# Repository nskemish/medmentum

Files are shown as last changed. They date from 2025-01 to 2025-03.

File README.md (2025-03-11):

<p align="center">
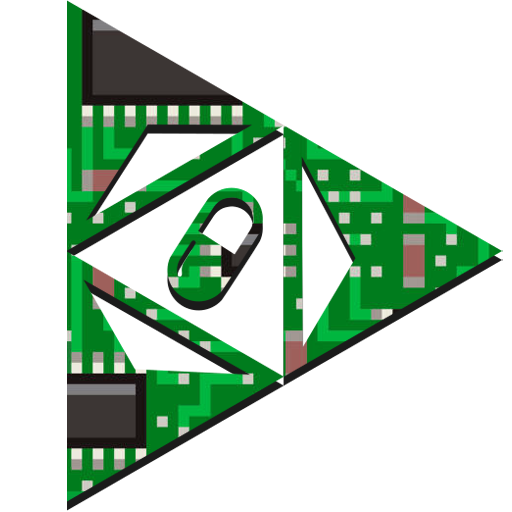
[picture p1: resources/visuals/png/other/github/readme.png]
  
</p>
<div align="center" id="toc">
  <ul style="list-style: none">
    <summary>
      <h1>MedMentum</h1><br>
      <h3 align="center">Automatski dozer za lekove</h3>
    </summary>
  </ul>
</div>

---

# Šta je to MedMentum?
**MedMentum** je revolucionarni sistem za automatsko doziranje lekova, osmišljen da transformiše način na koji pacijenti i zdravstveni radnici pristupaju terapijama. Ovaj inovativni uređaj kombiniuje najsavremeniju tehnologiju sa intuitivnim dizajnom kako bi omogućio precizno, sigurno i jednostavno doziranje lekova. MedMentum ne samo da olakšava svakodnevno uzimanje terapija, već i smanjuje rizik od ljudskih grešaka, čineći medicinsku negu pouzdanijom i efikasnijom. 💊✨

## Naša misija 

Naša misija je da revolucionišemo proces primene terapija kroz tehnološke inovacije. Želimo da smanjimo broj grešaka u doziranju lekova, povećamo svest o važnosti pravilnog uzimanja terapija i omogućimo pacijentima veću samostalnost u upravljanju svojim zdravljem. MedMentum je više od uređaja – to je alat koji podržava pacijente i zdravstvene radnike, čineći svakodnevne terapije jednostavnijim, sigurnijim i pristupačnijim. 

## Ciljevi 

1. **Preciznost**: MedMentum obezbeđuje tačno doziranje lekova u skladu sa propisanom terapijom, eliminišući mogućnost ljudske greške.   
2. **Sigurnost**: Pametni sigurnosni mehanizmi sprečavaju predoziranje ili propustanje doze, čime se povećava bezbednost pacijenata.   
3. **Pristupačnost**: Dizajniran je da bude jednostavan za korišćenje, kako bi odgovarao pacijentima svih uzrasta i zdravstvenih stanja.   
4. **Pouzdanost**: MedMentum pruža konzistentnu podršku, omogućavajući pacijentima da se oslanjaju na uređaj u svakodnevnom životu.   

## Ključne karakteristike 

- **Pametni uređaj za automatsko doziranje**: MedMentum automatski odmerava i dozira lekove prema unapred podešenom planu terapije. 
- **Integracija sa mobilnom aplikacijom**: Pacijenti i zdravstveni radnici mogu pratiti terapiju, primati podsetnici i prilagođavati doze putem jednostavne mobilne aplikacije.   
- **Notifikacije i podsetnici**: Sistem šalje obaveštenja za vreme uzimanja lekova, čime se smanjuje rizik od zaboravljanja. 
- **Sigurnosne funkcije**: Ugrađeni mehanizmi, poput zaključavanja i alarma, obezbeđuju da se lek uzima na pravi način i u pravo vreme.   
- **Moderan i ergonomski dizajn**: Uređaj je kompaktan, lak za nošenje i dizajniran da se uklopi u svakodnevni život korisnika. 

## Zašto je MedMentum neophodan? 

U današnjem svetu, gde su terapije sve složenije, a pacijenti često moraju da uzimaju više lekova dnevno, MedMentum predstavlja rešenje koje pojednostavljuje ovaj proces. Posebno je koristan za starije pacijente, one sa hroničnim bolestima ili pacijente koji imaju poteškoća u praćenju terapija. Zahvaljujući svojim pametnim funkcijama, MedMentum ne samo da poboljšava kvalitet života pacijenata, već i olakšava posao zdravstvenim radnicima, smanjujući opterećenje i rizik od grešaka. 🌍💪  

**MedMentum** je više od tehnologije – to je korak ka budućnosti u kojoj su terapije bezbednije, preciznije i pristupačnije za sve.

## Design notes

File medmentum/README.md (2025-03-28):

# medmentum

MedMentum aplikacija za precizno doziranje lekova

## Getting Started

This project is a starting point for a Flutter application.

A few resources to get you started if this is your first Flutter project:

- [Lab: Write your first Flutter app](https://docs.flutter.dev/get-started/codelab)
- [Cookbook: Useful Flutter samples](https://docs.flutter.dev/cookbook)

For help getting started with Flutter development, view the
[online documentation](https://docs.flutter.dev/), which offers tutorials,
samples, guidance on mobile development, and a full API reference.

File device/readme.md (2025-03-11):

# Projektna dokumentacija za uređaj

Ovaj folder sadrži sve fajlove i dokumentaciju vezanu za razvoj uređaja, uključujući hardverske komponente, mehanički dizajn i firmware.

## Struktura foldera

- **/hw**: Sadrži sve fajlove vezane za hardverski dizajn uređaja.
	- `$d/` - Folder sa simbolima, otiscima i 3D modelima.
	- `$bk/` - Folder sa rezervnim kopijama fajlova.
	- `$ds/` - Folder sa tehničkim dokumentacijama komponenti.
	- `$pr/` - Folder sa projektnim fajlovima.

- **/mh**: Sadrži fajlove vezane za mehanički dizajn uređaja.
  - `step/` - Modeli mehaničkih dijelova.
  - `elev/` - Kote dimenzija modela.
  - `stl/` - STL fajlovi za 3D štampu.

- **/fw**: Sadrži izvorni kod i dokumentaciju za firmware uređaja.
  - `src/` - Izvorni kod firmware-a.
    - `main.c` - Glavni programski kod.
    - `drivers/` - Drajveri za periferije.
  - `README.md` - Dokumentacija specifična za firmware.
  - `build/` - Kompajlirani fajlovi (opciono).

## Kako koristiti ovaj folder

### **Hardver**: 
Za pregled shematskih dijagrama i PCB dizajna, otvorite odgovarajuće fajlove u **`/hw`** folderu. 
Gerber fajlovi se mogu koristiti za naručivanje PCB-a.
> [!NOTE]
> Za otvaranje ovih fajlova potrebno je imati najnoviju verziju [KiCad-a](https://www.kicad.org/).

### **Mehanika**: 
3D modeli i 2D crteži se nalaze u **`/mh`** folderu. STL fajlovi su spremni za 3D štampu.

### **Firmware**: 
Izvorni kod firmware-a se nalazi u **`/fw/src`** folderu. Pratite uputstva u `readme.md` za kompilaciju i upload firmware-a na uređaj.

---

Za sva pitanja ili dodatne informacije, kontaktirajte:

- **Ognjen Guteša**  
  heyognjen@icloud.com  |  +381 63 532178

---
> [!WARNING]
> Ova dokumentacija je u razvoju i može biti ažurirana tokom projekta.

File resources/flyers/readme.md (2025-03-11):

# 🇷🇸
>[!IMPORTANT]
>**U ovom folderu se nalazi isključivo promotivni materijal.**

# 🇬🇧
>[!IMPORTANT]
>**This folder contains only promotional material.**

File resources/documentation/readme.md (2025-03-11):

# 🇷🇸
>[!IMPORTANT]
>**U ovom folderu se nalazi isključivo dokumentacija.**

# 🇬🇧
>[!IMPORTANT]
>**This folder contains only documentation.**

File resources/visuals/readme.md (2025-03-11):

# 🇷🇸
>[!IMPORTANT]
>**U ovom folderu se nalaze isključivo grafičke slike .png i .svg formata. Molimo Vas sortirajte formate po zadatim folderima (./png ./svg) neuključujući sprajtove (sprites), slike koje se koriste za ekran, koje su takođe .png formata. Soritrati sprajtove u ./sprites folder.**

# 🇬🇧
>[!IMPORTANT]
>**This folder contains exclusively graphic images in .png and .svg format. Please sort formats by default folders (./png ./svg) excluding sprites, images used for display, which are also .png format. Sort the sprites into the ./sprites folder.**

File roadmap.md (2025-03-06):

> [!IMPORTANT]
> *Ovde se nalaze svi zadaci i njihovi rokovi, ovim dokumentom se svi članovi tima moraju striktno pridržavati!*

 **1A Hardver** <sup>***End Date: 14. Feb***</sup>
 ---
 ### **1A1 Šeme**  <sup>***End Date: 7. Feb***</sup>

***1A101*** – Podesavanje radnog okruženja  
***1A102*** – Pronalaženje potrebnih komponenti u skladu sa trenutnim sektorom  
***1A103*** – Prikupljanje materijala: simbole, kućišta, tehničke liste, 3D modele  
***1A104*** – Kreiranje blokova  
***1A105*** – Provera pojedinačnih blokova  
***1A106*** – Spajanje blokova u sektore  
***1A107*** – Provera gotove šeme

### **1A2 PCB**  <sup>***End Date: 14. Feb***</sup>

***1A201*** – Podesavanje radnog okruženja  
***1A202*** – Postavljanje blokova  
***1A203*** – Postavljanje sektora  
***1A204*** – Definisanje dimenzija ploče  
***1A205*** – Postavljanje sektora na ploču  
***1A206*** – Provera ploče  
***1A207*** – Priprema za EMC testove

**1B Firmver** <sup>***End Date: 28. Feb***</sup>
---
### **1B1 Južni most** <sup>***End Date: 21. Feb***</sup>

***1B101*** – Podesavanje radnog okruženja  
***1B102*** – Programiranje bootloader-a  
***1B103*** – Programiranje drajvera  
***1B104*** – Programiranje funkcionalnih blokova  
***1B105*** – Programiranje komunikacije sa severnim mostom

### **1B2 Severni most**  <sup>***End Date: 28. Feb***</sup>

***1B201*** – Podesavanje radnog okruženja  
***1B202*** – Programiranje bootloader-a  
***1B203*** – Programiranje drajvera  
***1B204*** – Programiranje funkcionalnih blokova  
***1B205*** – Programiranje komunikacije sa južnim mostom

**1C Mehanika** <sup>***End Date: 26. Mar***</sup>
---
### **1C1 Pokretni delovi**  <sup>***End Date: 14. Mar***</sup>

***1C101*** – Dizajn unutrašnjeg sistema za doziranje  
***1C102*** – Dizajn šaržera  
***1C103*** – Dizajn zaštite upravljanja

### **1C2 Estetika**  <sup>***End Date: 26. Mar***</sup>

***1C201*** – Dizajn kućišta  
***1C202*** – Dizajn pozicije ekrana  
***1C203*** – Dizajn za čitač otisaka prstiju

**2A Papirologija** <sup>***End Date: 20. Mar***</sup>
---
### **2A1 Korisnička Dokumentacija** <sup>***End Date: 30. Jan***</sup>

***2A101*** – Opšti pasusi \
***2A102*** – Problemi i rešenja korisnika	\
***2A103*** – Pravljenje ankete za ciljnu grupu korisnika	\
***2A104*** – Rezultati ankete i zaključci	

### **2A2 Tehnička Dokumentacija** <sup>***End Date: 20. Mar***</sup>

***2A201*** - Tehnički zapis elektronike za južni most \
***2A202*** - Tehnički zapis elektronike za severni most	\
***2A203*** - Tehnički zapis firmvera za južni most	\
***2A204*** - Tehnički zapis firmvera za severni most \
***2A205*** - Tehničko objašnjenje za mehanički spektar uredjaja \
***2A206*** - Objašnjenje iza pojedinih specifičnih izbora	

---

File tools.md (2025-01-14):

# Alati
## **GitHub**
---
### 1. **GitHub Desktop**
GitHub Desktop je jednostavan alat za upravljanje Git projektima putem grafičkog korisničkog interfejsa. Idealno je za korisnike koji nisu upoznati sa komandnom linijom.  
🔗 [Preuzmite GitHub Desktop](https://desktop.github.com/)

---
### 2. **Git dokumentacija**
Git je alat za praćenje verzija koji omogućava rad sa kodom u timu. GitHub koristi Git u pozadini, tako da je razumevanje osnovnih komandi ključno.  
🔗 [Git dokumentacija](https://git-scm.com/doc)  
🔗 [Osnovne Git komande – vodič](https://git-scm.com/book/en/v2/Getting-Started-About-Version-Control)

---

## Osnovni koncepti korišćenja Git-a i GitHub-a

1. **Repository (Repozitorijum)**: Centralno mesto gde se čuva vaš kod i istorija promena.  
2. **Branch (Grana)**: Paralelna verzija repozitorijuma koja vam omogućava da radite na različitim funkcionalnostima bez ometanja glavne verzije.  
3. **Commit**: Snimanje promena u kodu zajedno sa opisom onoga što je promenjeno.  
4. **Push i Pull**: Slanje vaših promena na GitHub server (push) i preuzimanje najnovijih promena (pull).  
5. **Pull Request**: Predlog za spajanje promena iz jedne grane u drugu.

---

## Korisni resursi

- Detaljna uputstva: [GitHub dokumentacija](https://docs.github.com/en)  
- Tutorijali za početnike: [GitHub Learning Lab](https://lab.github.com/)  
- GitHub Desktop vodič: [Zvanični vodič](https://docs.github.com/en/desktop)

---

### **Alati za Elektroniku**
- **KiCad**: Open-source softver za dizajn štampanih ploča (PCB). Omogućava dizajn kompleksnih elektronskih sklopova, od šematskog dijagrama do proizvodnje PCB-a.  
- **Saturn PCB Toolkit**: Pomoćni alat za inženjere koji olakšava proračune impedanse, širine provodnika i ostalih kritičnih parametara u dizajnu PCB-a.  
- **LTSpice**: Softver za simulaciju elektronskih kola. Koristimo ga za analizu i optimizaciju performansi elektronskih sklopova pre nego što se izrade fizički prototipi.  

---

### **Alati za Mehaniku**
- **Autodesk Inventor**: Profesionalni alat za 3D modeliranje i projektovanje mehaničkih delova i sklopova. Omogućava detaljan dizajn, testiranje i analizu pre proizvodnje.  
- **FreeCAD**: Open-source softver za parametarsko 3D modelovanje. Idealan za manje kompleksne projekte i za brze iteracije u razvoju.  

---

### **Alati za Programiranje**
- **Flutter SDK**: Framework za razvoj mobilnih aplikacija. Koristimo ga za brzi razvoj aplikacija koje rade na više platformi, uz odlične performanse i moderno korisničko iskustvo.  
- **VSCode (Visual Studio Code)**: Lak i moćan uređivač koda sa podrškom za brojne jezike i ekstenzije. Koristimo ga za razvoj aplikacija i rad sa različitim programskim jezicima.  

---

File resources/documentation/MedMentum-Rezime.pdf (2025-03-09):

1

,,MedMentum” - automatizovani dozer za lekove ,,MedMentum” - automated medication dispenser

Autori: Ognjen Guteša-T31, David Konecky-T31, Sofija Zuber-R31 ; ETŠ „Mihajlo Pupin“ - Novi Sad
Mentor: Novica Gutović, dipl. inž. elektrotehnike, predmetni nastavnik;

REZIME

MedMentum je uređaj dizajniran za precizno automatsko doziranje lekova pacijentima, sa ciljem poboljšanja terapije i smanjenja grešaka u doziranju. Osigurava pravovremeno uzimanje terapije prema unapred definisanim vremenskim intervalima i omogućava praćenje trenutnih zaliha lekova. U kombinaciji sa aplikacijom, korisnicima omogućava jednostavan uvid u preostalu količinu lekova i njihov raspored. MedMentum takođe šalje obaveštenja o nepravilnostima, čime povećava sigurnost i pouzdanost lečenja.

PRINCIP RADA I PRAKTIČNA REALIZACIJA

MedMentum koristi mikrokontroler STM32F411xxxx(13), koji upravlja celokupnom pločom i omogućava precizno upravljanje sistemom doziranja. Ovaj mikrokontroler je opremljen sa Cortex-M4 jezgrom, što omogućava visok nivo obrade podataka, kao i visoku efikasnost u pogledu energetske potrošnje. Zbog svoje niske potrošnje energije, STM32F411xxxx je idealan za dugotrajan rad u IoT okruženju, čineći ga savršenim izborom za uređaje poput MedMentuma, koji zahteva dugotrajnu autonomiju.
Pored STM32F411, uređaj koristi ESP32-C3(1), koji omogućava online komunikaciju sa MQTT serverom. Ovaj čip omogućava daljinsko praćenje i kontrolu terapije putem interneta, omogućavajući korisnicima da u realnom vremenu povežu svoj uređaj sa MedMentum mobilnom aplikacijom. Uređaj je takođe opremljen sa Battery Management System (BMS)(2)-(9), zasnovanim na čipu BQ24074(2), koji osigurava efikasno punjenje baterije, zaštitu od prekomernog pražnjenja i stabilan rad tokom dužeg vremenskog perioda. BQ24074 čip omogućava sigurno i optimalno upravljanje napajanjem uređaja, čime se produžava radni vek baterije i povećava pouzdanost sistema.Izbacivanje lekova se vrši pomoću nekoliko servo motora i dispenzera za lekovekoji se zajedno sa matičnom pločom (Sl.2) MedMentuma nalaze u posebnom plastičnom kućištu.

Kombinacija ovih komponenti omogućava MedMentumu da funkcioniše kao efikasan, dugotrajan i pouzdan uređaj za automatsko doziranje lekova, koji korisnicima omogućava jednostavno i sigurno upravljanje terapijama u svakodnevnom životu.

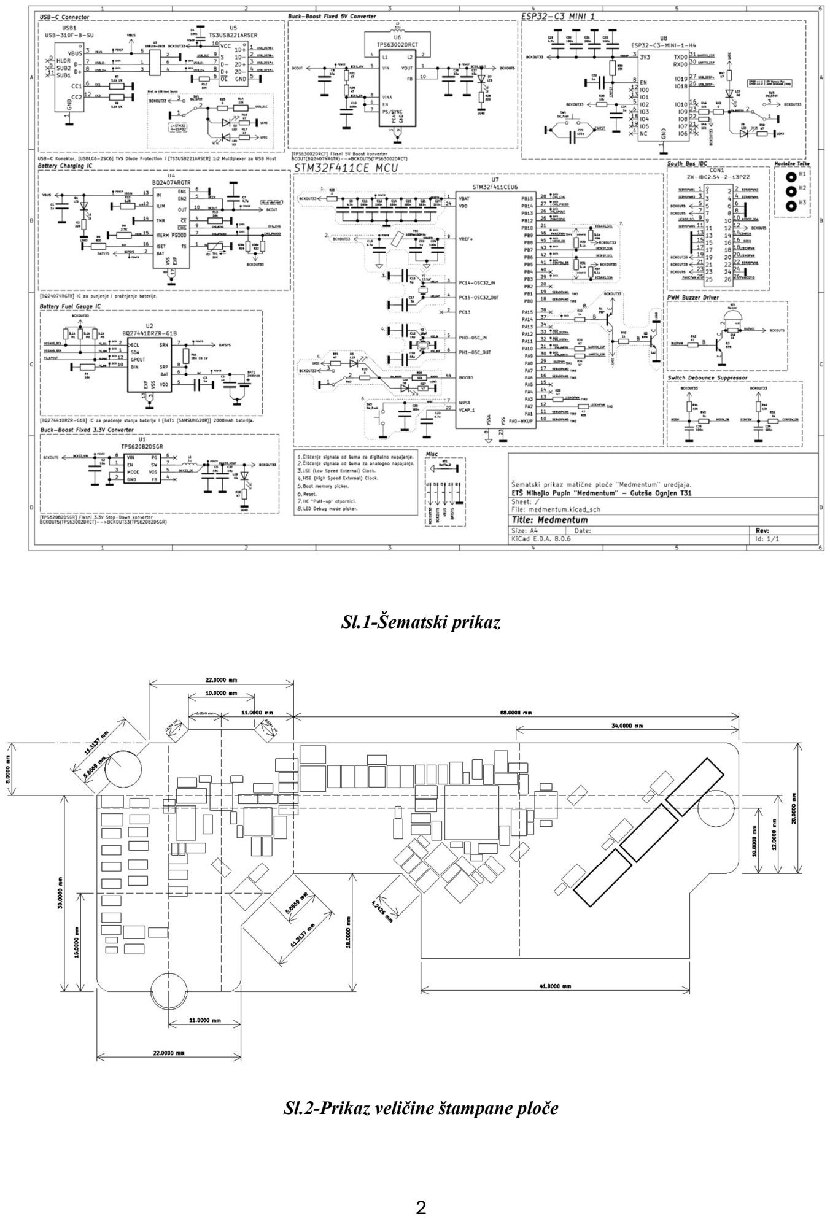
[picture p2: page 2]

2

Sl.1-Šematski prikaz

Sl.2-Prikaz veličine štampane ploče

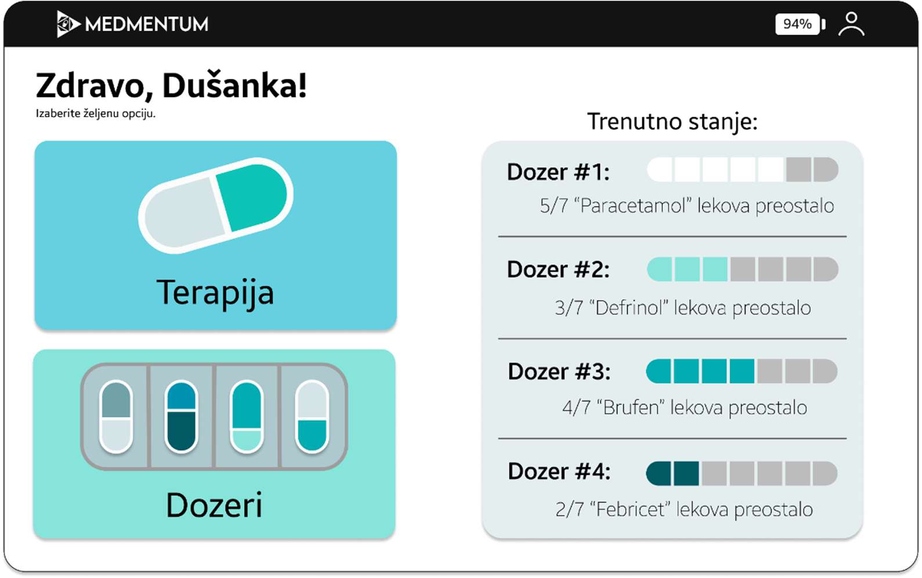
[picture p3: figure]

3

Aplikacija (Sl.3)
Naša aplikacije je izvedena tako da na što jednostavniji način našim korisnicima pruži informacije o uređaju ali i o njihovoj terapiji. Neke od informacija koje se mogu videti na aplikaciji su: sadržaj terapiji, zalihe lekova u uređaju,kao i baterija u uređaju.
Aplikacija je razvijena koristeći Flutter, moderni framework koji omogućava kreiranje brzih i responzivnih mobilnih aplikacija za više platformi, kao što su iOS i Android. Aplikacija koju smo samostalno razvili koristi Figmu za dizajn korisničkog interfejsa, što omogućava laku saradnju i brzu izradu vizuelnih prototipova. Korišćenjem Figma alata, osiguravamo da dizajn bude dosledan i jednostavan za korišćenje.

Sl.3-Početna strana aplikacije

REZULTAT

MedMentum je sistem koji je razvijen sa ciljem poboljšanja i olakšanja svakodnevnog uzimanja terapije, kako bi se smanjile greške u doziranju i poboljšala sigurnost lečenja.
Ovaj sistem omogućava precizno automatsko doziranje lekova, osigurava pravovremeno uzimanje terapije prema unapred definisanim vremenskim intervalima i praćenje trenutnih zaliha lekova. U kombinaciji sa mobilnom aplikacijom, korisnici mogu lako pratiti preostalu količinu lekova i njihov raspored. Takođe, sistem šalje obaveštenja u slučaju nepravilnosti, što značajno povećava bezbednost i pouzdanost lečenja.
Kroz istraživanje koje smo sproveli putem anketa, dobili smo povratne informacije od potencijalnih korisnika koji su izrazili veliko interesovanje i potrebu za ovakvim uređajem. Rezultati ankete pokazali su da korisnici smatraju da su greške u terapiji česta pojava i da bi MedMentum mogao značajno uticati na poboljšanje ovog aspekta.

4

ZAKLJUČAK

Prednosti sistema uključuju pravovremeno uzimanje terapije, praćenje trenutnih zaliha lekova i obaveštavanje o nepravilnostima, čime se značajno povećava sigurnost pacijenata. Korišćenjem aplikacije, korisnicima je omogućeno jednostavno praćenje količine lekova i njihovog rasporeda.
Iako sistem donosi brojne prednosti u odnosu na tradicionalne metode uzimanja lekova, potrebno je i dalje raditi na njegovom usavršavanju. Na primer, implementacija novih funkcionalnosti u aplikaciji, kao i mogućnost proširenja uređaja za dodatne terapije, može poboljšati korisničko iskustvo. Takođe, s obzirom na specifične potrebe različitih korisnika, mogu se dalje razraditi personalizovane opcije. MedMentum predstavlja značajan napredak u ovom domenu, ali dalji rad na unapređenju sistema može dodatno poboljšati njegovu efikasnost i zadovoljstvo korisnika.

ZAHVALNICE
Ovom prilikom se zahvaljujemo:Novici Gutoviću na pruženoj tehničkoj podršci pri realizaciji ovog uređaja, TeamCad-u D.O.O i njihovim zaposlenima na usluživanju 3D štampača, kao i razrednim starešinama Aleksandri Rakić Todorović i Martini Janjanin na pruženoj podršci tokom realizacije ovog projekta.

LITERATURA I REFERENCE
(1)https://www.espressif.com/sites/default/files/documentation/esp32-c3-mini-1_datasheet_en.pdf
(2)BQ2407x Standalone 1-Cell 1.5-A Linear Battery Charger with PowerPath datasheet (Rev. N)
(3)https://www.ti.com/lit/ds/symlink/bq27441-g1.pdf (4)https://docs.rs-online.com/84c8/0900766b812fdd47.pdf (5)https://www.ti.com/lit/ds/symlink/tps62082.pdf?ts=1741093078565&ref_url=https%253A %252F%252Fwww.ti.com%252Fproduct%252FTPS62082 (6)https://www.ti.com/lit/ds/symlink/tps63002.pdf?ts=1741093219895&ref_url=https%253A %252F%252Fwww.bing.com%252F (7)https://www.ti.com/lit/ds/symlink/ts3usb221a.pdf?ts=1741074629221&ref_url=https%253 A%252F%252Fwww.ti.com%252Fproduct%252FTS3USB221A (8)https://www.lcsc.com/datasheet/lcsc_datasheet_2410122028_HOOYA-USB-310F-B-SU_C309365.pdf
(9)https://www.st.com/resource/en/datasheet/usblc6-2.pdf
(10)https://jlcpcb.com/
(11)https://flutter.dev/
(12)https://www.figma.com/(13)https://www.st.com/resource/en/datasheet/stm32f411re.pdf

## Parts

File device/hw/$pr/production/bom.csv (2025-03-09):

Reference | Value | Footprint | Qty | DNP | LCSC Part
CON1 | ZX-IDC2.54-2-13PZZ | fpl:IDC-TH_26P-P2.54_ZX-IDC2.54-2-13PZZ | 1 |  | C7501247
BAT1 | 2000mAh | fpl:BATTERY-SMD_18650-1S-L77.1-W20.7-1 | 1 |  | C5371778
L2 | 2.2u | Inductor_SMD:L_1008_2520Metric | 1 |  | C3002551
U8 | ESP32-C3-MINI-1-H4 | fpl:ESP32-C3-MINI-1-H4 | 1 |  | C2934569
C16,C17 | 5p | Capacitor_SMD:C_0402_1005Metric | 2 |  | C880630
R11 | 10m 1% 1W | Resistor_SMD:R_1206_3216Metric | 1 |  | C601085
U1 | TPS62082DSGR | fpl:TPS62082DSGR | 1 |  | C485809
U2 | BQ27441DRZR-G1B | fpl:BQ27441DRZR-G1B | 1 |  | C473374
USB1 | USB-310F-B-SU | fpl:USB-310F-B-SU | 1 |  | C309365
Y2 | 18pF | Crystal:Crystal_SMD_3225-4Pin_3.2x2.5mm | 1 |  | C179641
Y1 | 12.5pF | Crystal:Crystal_SMD_3215-2Pin_3.2x1.5mm | 1 |  | C130253
U5 | TS3USB221ARSER | fpl:TS3USB221ARSER | 1 |  | C128396
U6 | TPS63002DRCT | fpl:TPS63002DRCR | 1 |  | C116655
SW1,SW2,SW5 | SW_SPDT | fpl:SW-SMD_K3-1235S-K1 | 3 |  | C92660
SW3,SW4 | SW_Push | fpl:KEY-SMD_4P-L6.0-W6.0-P4.50-LS10.0 | 2 |  | C83916
BZ1 | Buzzer | fpl:BUZ-TH_BD17.0-P10.00-D0.8 | 1 |  | C76872
U7 | STM32F411CEU6 | fpl:STM32F411CEU6 | 1 |  | C60420
U4 | BQ24074RGTR | fpl:BQ24074RGTR | 1 |  | C54313
C18,C19 | 16p | Capacitor_SMD:C_0402_1005Metric | 2 |  | C48836
R7,R8 | 5.1k 1% | Resistor_SMD:R_0402_1005Metric | 2 |  | C25905
R1,R2,R5,R30,R31,R36,R37 | 5.1k | Resistor_SMD:R_0402_1005Metric | 7 |  | C25905
R19,R22 | 100k | Resistor_SMD:R_0603_1608Metric | 2 |  | C25803
R4,R12,R13,R14,R26,R38,R39,R41,R44,R46,R49 | 10k | Resistor_SMD:R_0402_1005Metric | 11 |  | C25744
R6 | 820 | Resistor_SMD:R_0603_1608Metric | 1 |  | C23253
R16,R17,R18,R21,R24,R25,R27,R29,R33,R34,R35,R42,R47,R50 | 47 | Resistor_SMD:R_0603_1608Metric | 14 |  | C23182
R3,R28 | 220 | Resistor_SMD:R_0603_1608Metric | 2 |  | C22962
R10 | 1.2K | Resistor_SMD:R_0603_1608Metric | 1 |  | C22765
Q2,Q3 | NPN | Package_TO_SOT_SMD:SOT-23 | 2 |  | C20526
R15,R20,R23,R43 | 0 | Resistor_SMD:R_0805_2012Metric | 4 |  | C17477
C2,C5,C8,C26,C27,C37 | 10u | Capacitor_SMD:C_0805_2012Metric | 6 |  | C15850
C1,C3,C6,C22,C32,C34,L1 | 1u | Capacitor_SMD:C_0603_1608Metric | 7 |  | C15849
R32,R40,R45,R48,R51 | 1k | Resistor_SMD:R_0603_1608Metric | 5 |  | C14676
C4,C10,C11,C12,C14,C15,C20,C21,C24,C25,C29,C30,C31,C33,C35,C36 | 100n | Capacitor_SMD:C_0603_1608Metric | 16 |  | C14663
TH1 | 10K | Resistor_SMD:R_0603_1608Metric | 1 |  | C13564
R9 | 2.7K | Resistor_SMD:R_0603_1608Metric | 1 |  | C13167
U3 | USBLC6-2SC6 | fpl:USBLC6-2SC6 | 1 |  | C7519
D1,D4,D7 | LED | LED_SMD:LED_0805_2012Metric | 3 |  | C2297
D2,D3,D5,D6,D8,D9 | LED | LED_SMD:LED_0603_1608Metric | 6 |  | C2290
Q1 | PNP | Package_TO_SOT_SMD:SOT-23 | 1 |  | C2143
C7,C9,C13,C23,C28 | 4.7u | Capacitor_SMD:C_0805_2012Metric | 5 |  | C1779
FB1 | 100R@100MHz | Inductor_SMD:L_0805_2012Metric | 1 |  | C1015
J1,J2,J3,J4,J5 | Conn_01x01_Pin | fpl:EPMM | 5

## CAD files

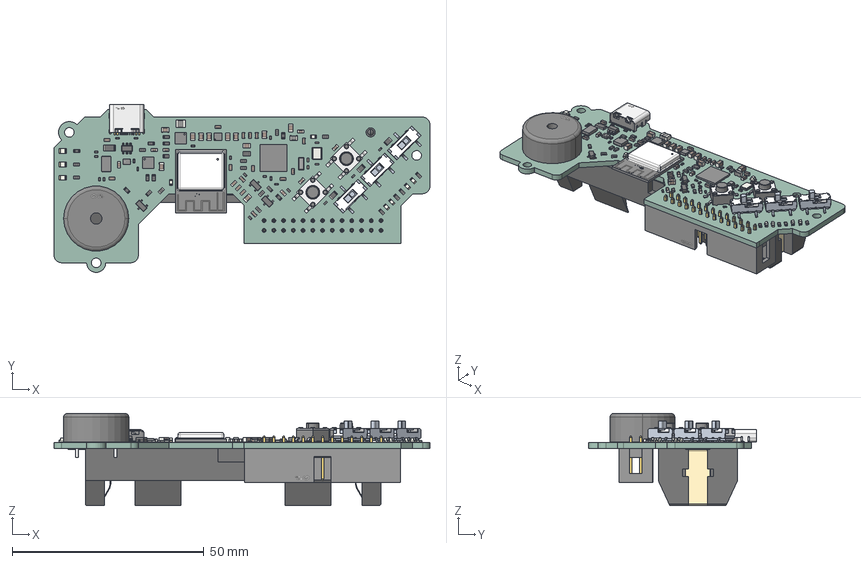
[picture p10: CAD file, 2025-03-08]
device/mh/medmentum.step
98.0 x 43.7 x 24.1 mm
SW-SMD_K3-1235S-K1 x 3
C_0603_1608Metric x 23
LED_0603_1608Metric x 6
C_0805_2012Metric x 11
R_0603_1608Metric x 27
R_0402_1005Metric x 20
L_1008_2520Metric
C_0402_1005Metric x 4
WIFIM-SMD_ESP32-C3-MINI-1
KEY-SMD_4P-L6.0-W6.0-P4.50-LS10.0 x 2
R_0805_2012Metric x 4
L_0805_2012Metric
LED_0805_2012Metric x 3
Crystal_SMD_3215-2Pin_3.2x1.5mm
BQ27410DRZR-G1
SOT_23_6
DRV8837DSGR
USB-3.1-SMD_16P-L8.9-W7.3-H3.3-P0.5
R_1206_3216Metric
DRC10
Crystal_SMD_3225-4Pin_3.2x2.5mm
SOT_23 x 3
UQFN-10_L2.0-W1.5-H0.6-P0.50
BUZ-TH_BD17.0-H7.5-P10.0
STM32F411CEU6
RGT16
BATTERY-SMD_18650-1S-L77.1-W20.7-1
IDC-TH_26P-P2.54_ZX-IDC2.54-2-13PZZ
_autosave-medmentum_PCB

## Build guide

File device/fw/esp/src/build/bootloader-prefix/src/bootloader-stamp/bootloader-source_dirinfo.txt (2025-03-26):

# This is a generated file and its contents are an internal implementation detail.
# The download step will be re-executed if anything in this file changes.
# No other meaning or use of this file is supported.

method=source_dir
command=
source_dir=C:/medmentum/device/fw/esp/tools/espidf/v5.4/esp-idf/components/bootloader/subproject
work_dir=

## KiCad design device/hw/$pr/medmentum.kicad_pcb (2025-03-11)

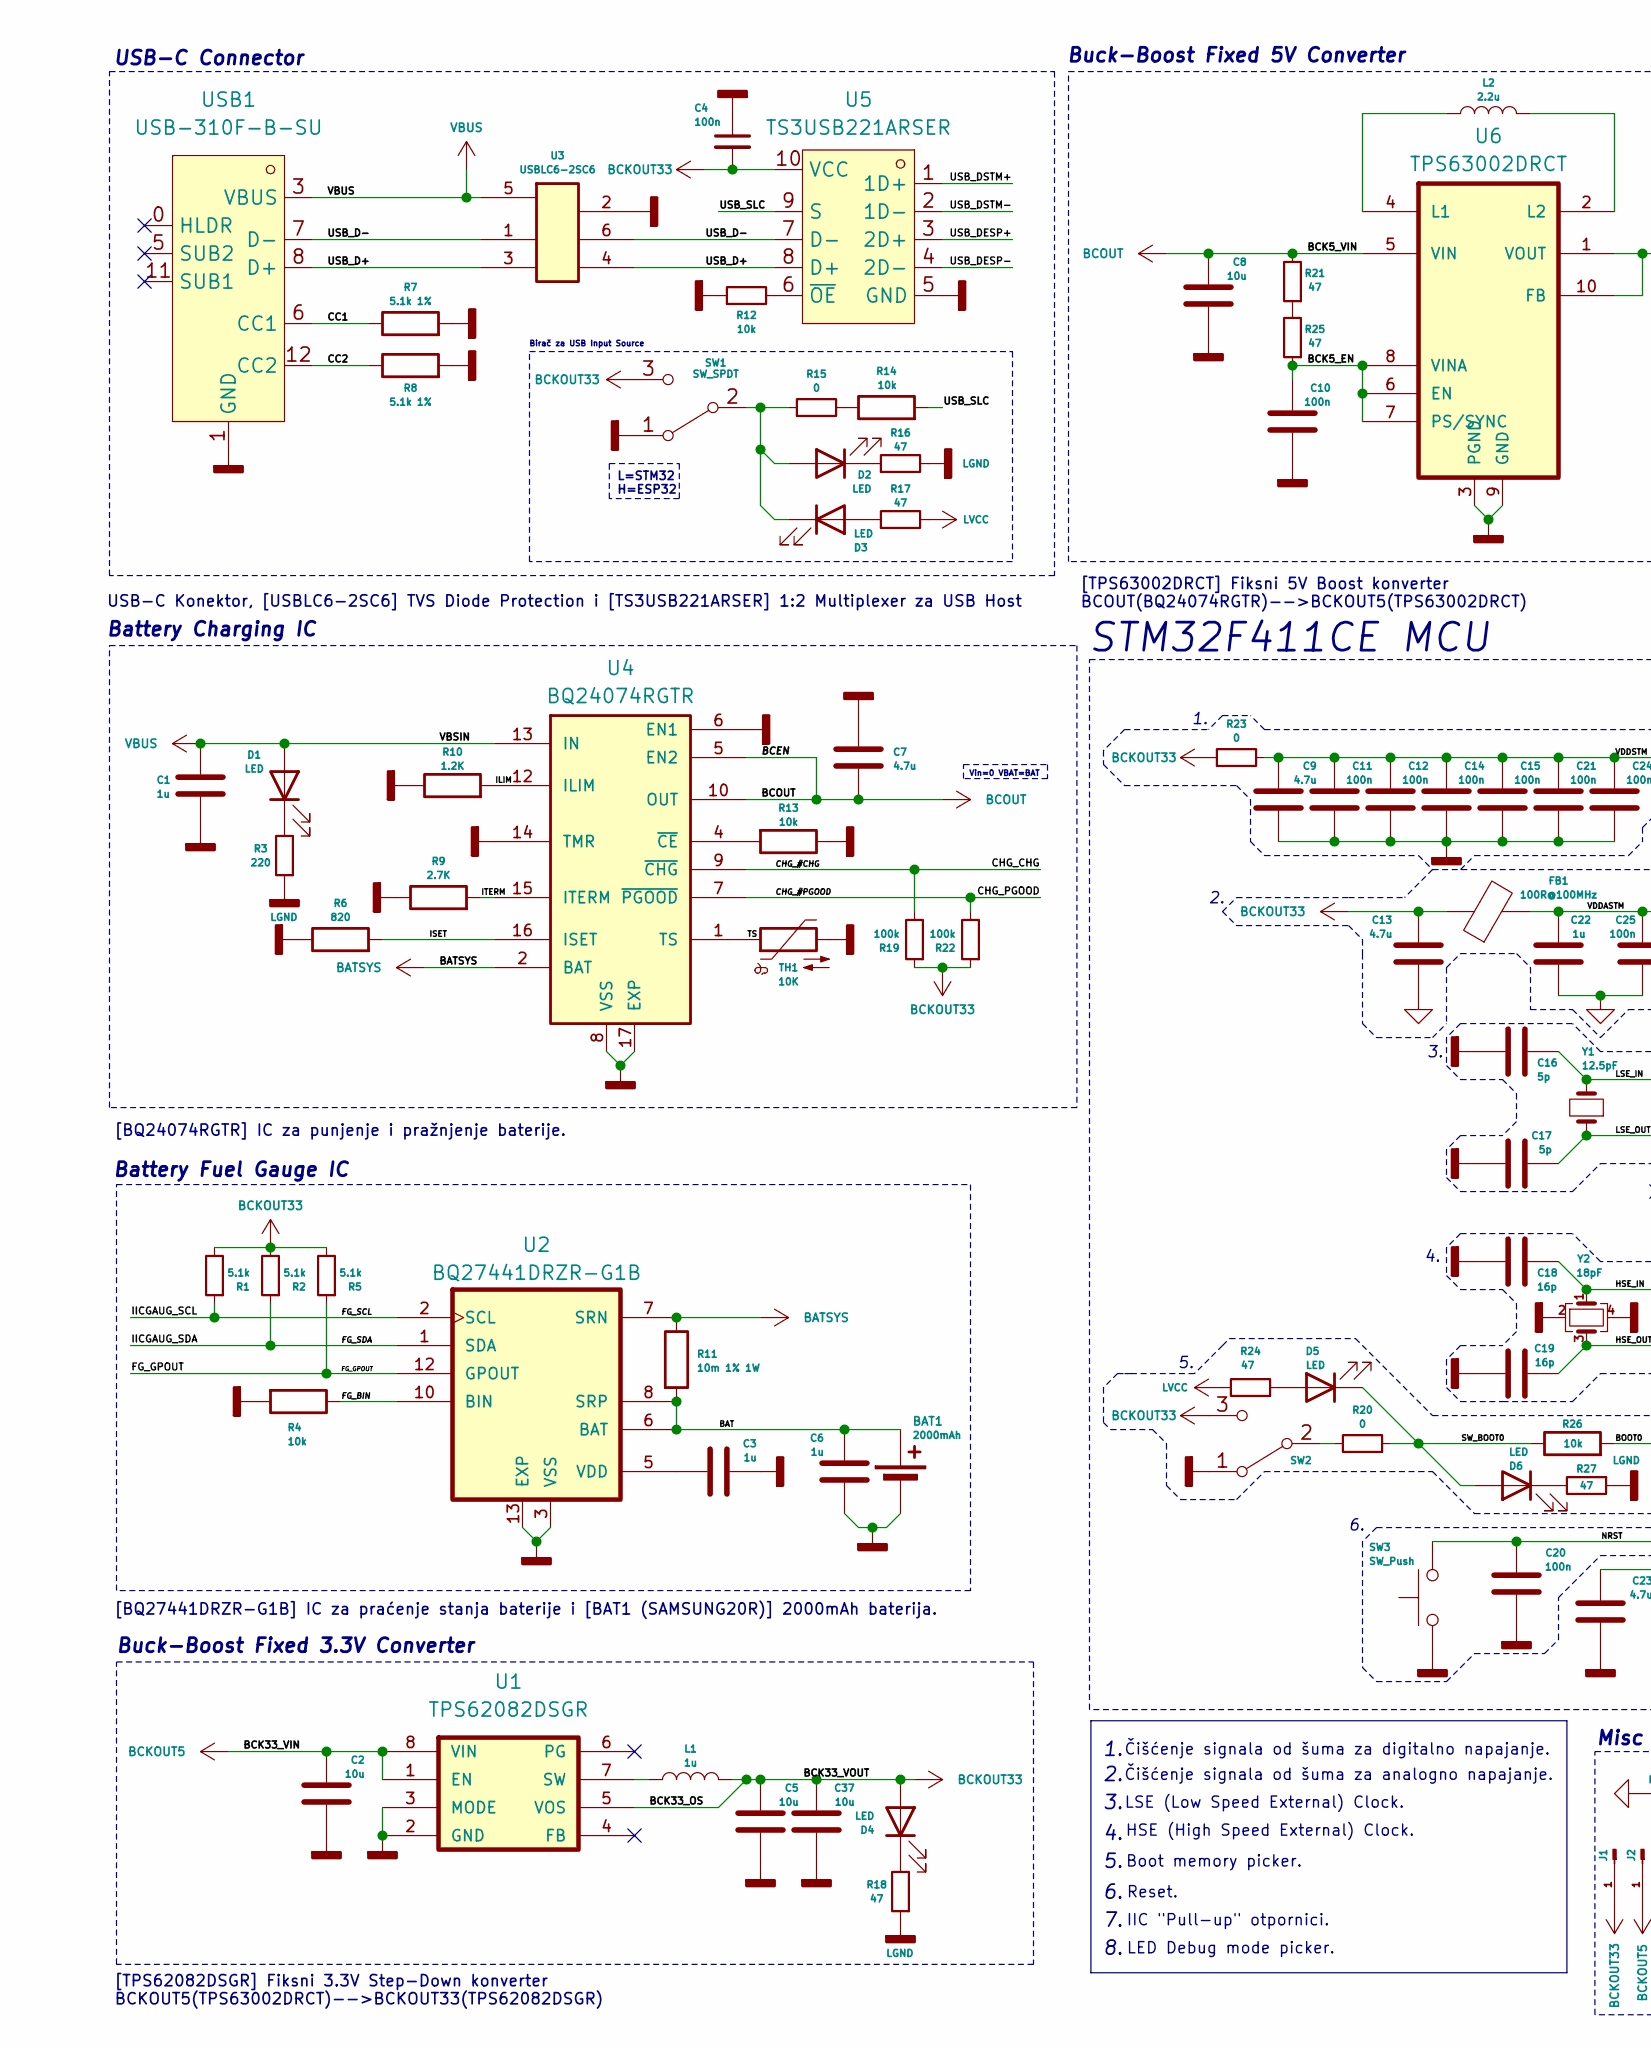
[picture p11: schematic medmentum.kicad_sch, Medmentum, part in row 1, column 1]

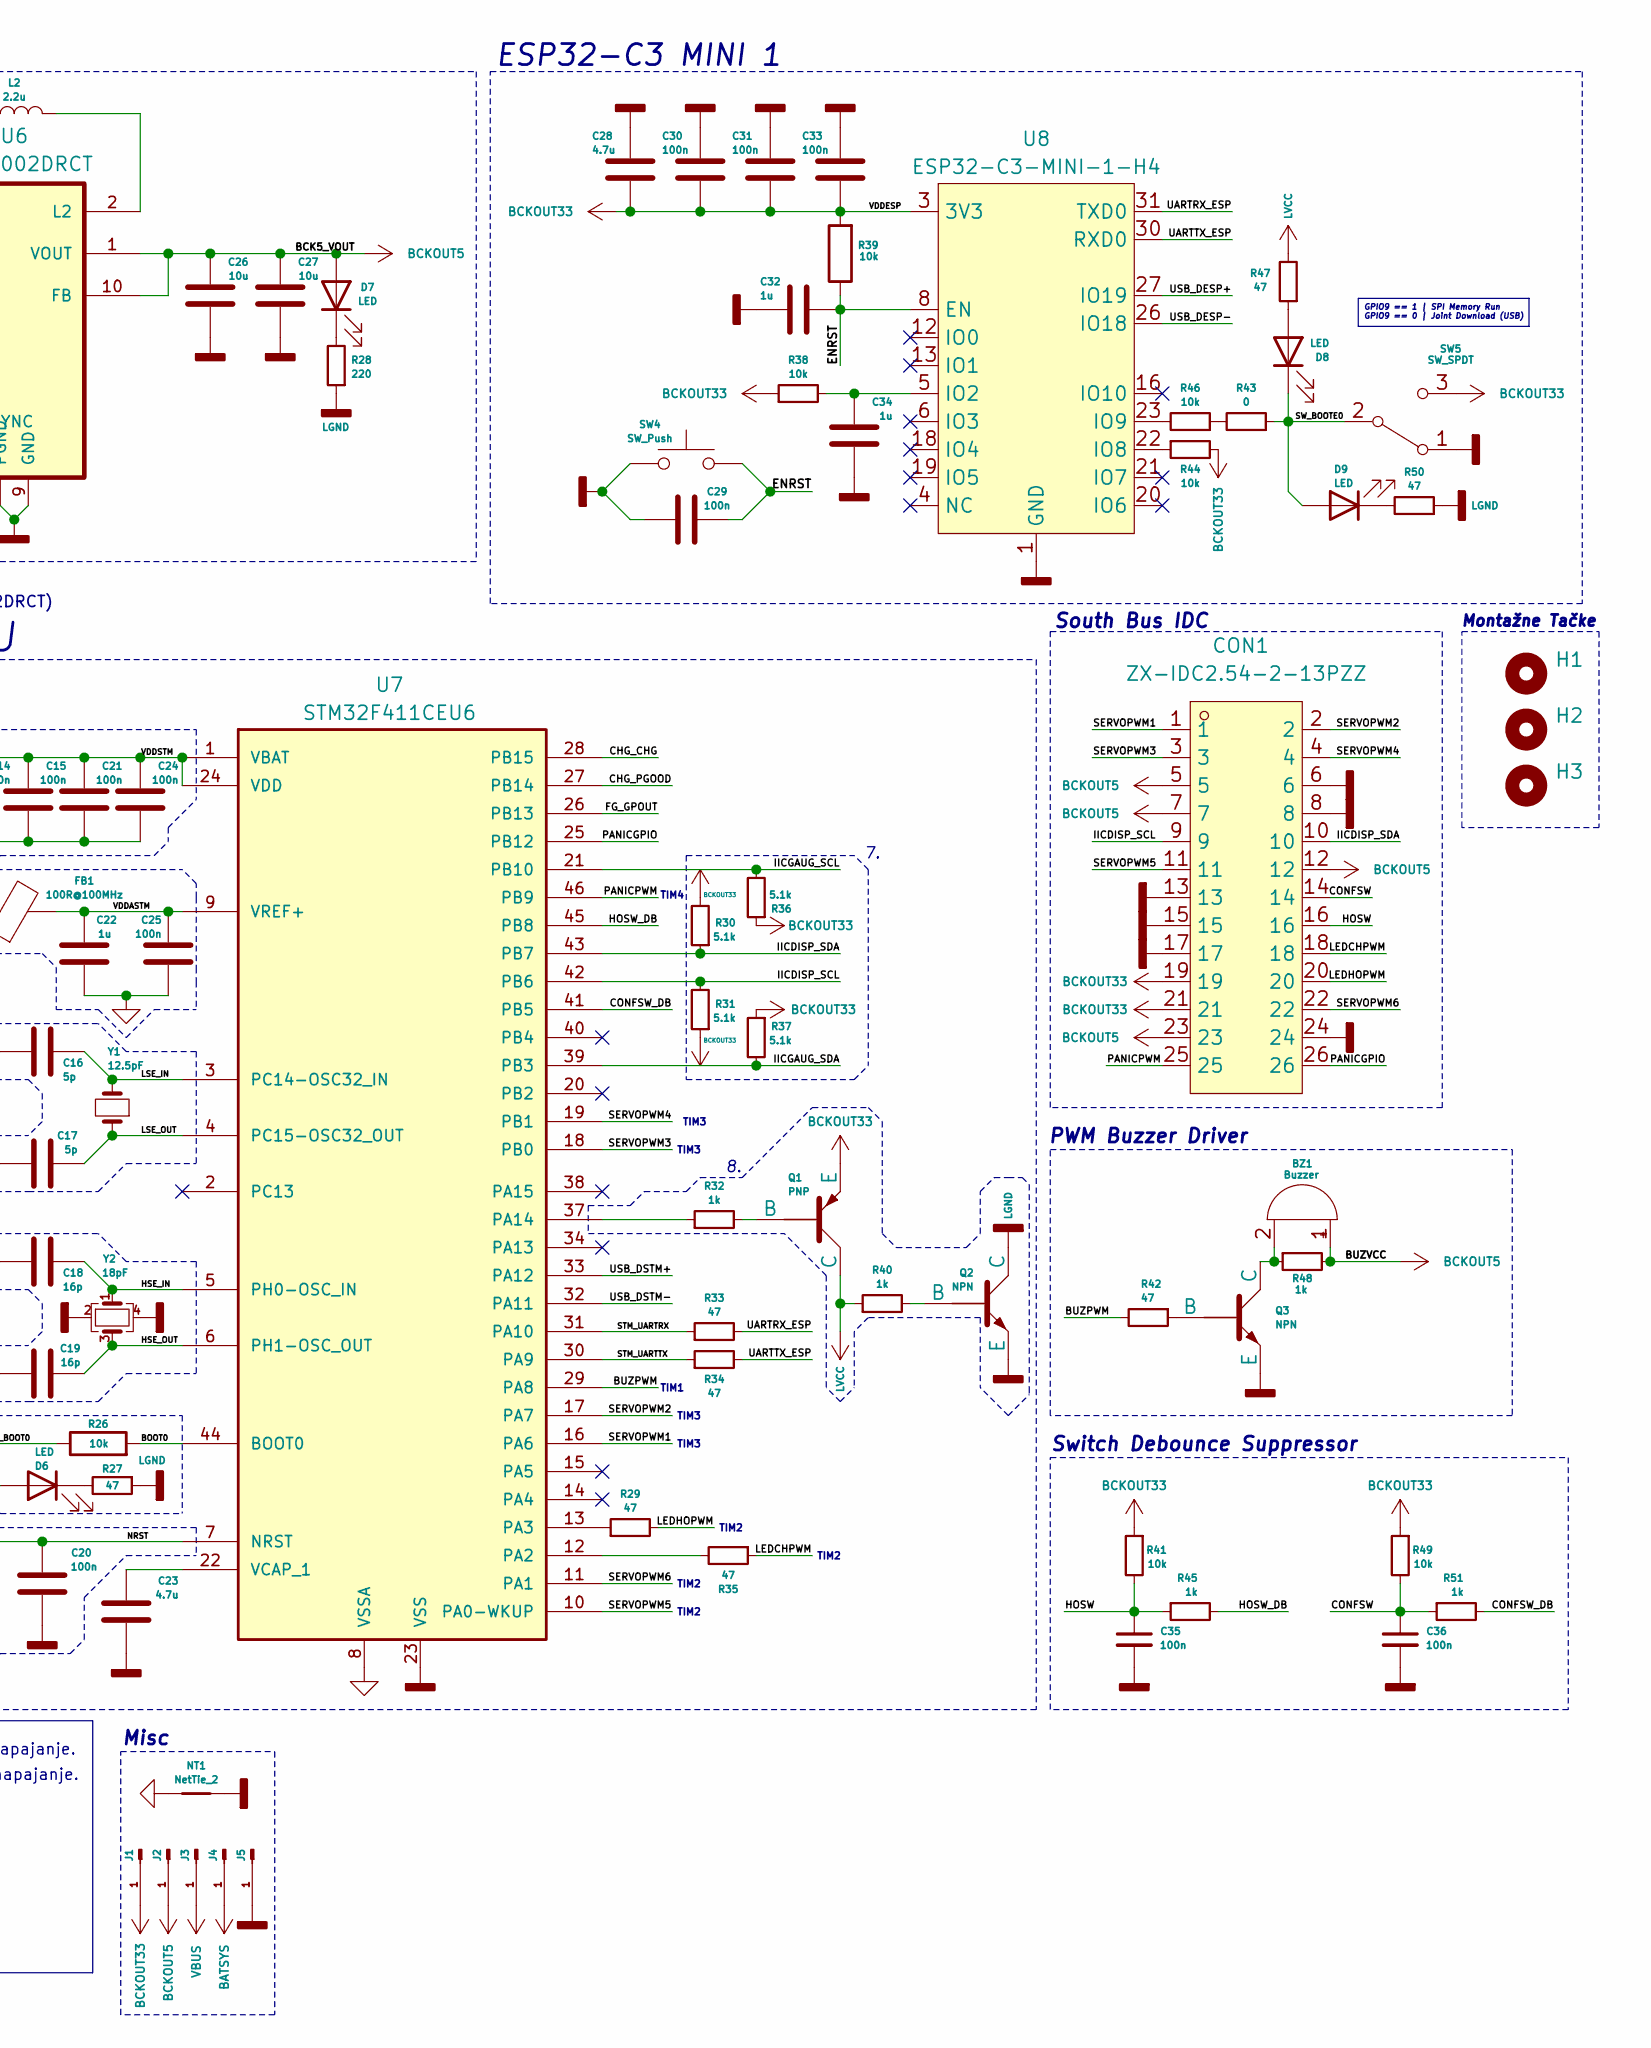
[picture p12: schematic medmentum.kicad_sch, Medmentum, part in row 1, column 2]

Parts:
BAT1: 2000mAh; BATTERY-SMD_18650-1S-L77.1-W20.7-1; LCSCPart C5371778
BZ1: Buzzer; BUZ-TH_BD17.0-P10.00-D0.8; LCSCPart C76872
C1, C3, C6, C22, C32, C34: 1u; C_0603_1608Metric; LCSCPart C15849
C2, C5, C8, C26, C27, C37: 10u; C_0805_2012Metric; LCSCPart C15850
C4, C10, C11, C12, C14, C15, C20, C21, C24, C25, C29, C30, C31, C33, C35, C36: 100n; C_0603_1608Metric; LCSCPart C14663
C7, C9, C13, C23, C28: 4.7u; C_0805_2012Metric; LCSCPart C1779
C16, C17: 5p; C_0402_1005Metric; LCSCPart C880630
C18, C19: 16p; C_0402_1005Metric; LCSCPart C48836
CON1: ZX-IDC2.54-2-13PZZ; IDC-TH_26P-P2.54_ZX-IDC2.54-2-13PZZ; LCSCPart C7501247
D1, D4, D7: LED; LED_0805_2012Metric; LCSCPart C2297
D2, D3, D5, D6, D8, D9: LED; LED_0603_1608Metric; LCSCPart C2290
FB1: 100R@100MHz; L_0805_2012Metric; LCSCPart C1015
H1, H2, H3: MountingHole_2.5mm
J1, J2, J3, J4, J5: Conn_01x01_Pin; EPMM
L1: 1u; C_0603_1608Metric; LCSCPart C15849
L2: 2.2u; L_1008_2520Metric; LCSCPart C3002551
NT1: NetTie_2; NetTie-2_SMD_Pad0.5mm
Q1: PNP; SOT-23; LCSCPart C2143
Q2, Q3: NPN; SOT-23; LCSCPart C20526
R1, R2, R5, R30, R31, R36, R37: 5.1k; R_0402_1005Metric; LCSCPart C25905
R3, R28: 220; R_0603_1608Metric; LCSCPart C22962
R4, R12, R13, R14, R26, R38, R39, R41, R44, R46, R49: 10k; R_0402_1005Metric; LCSCPart C25744
R6: 820; R_0603_1608Metric; LCSCPart C23253
R7, R8: 5.1k 1%; R_0402_1005Metric; LCSCPart C25905
R9: 2.7K; R_0603_1608Metric; LCSCPart C13167
R10: 1.2K; R_0603_1608Metric; LCSCPart C22765
R11: 10m 1% 1W; R_1206_3216Metric; LCSCPart C601085
R15, R20, R23, R43: 0; R_0805_2012Metric; LCSCPart C17477
R16, R17, R18, R21, R24, R25, R27, R29, R33, R34, R35, R42, R47, R50: 47; R_0603_1608Metric; LCSCPart C23182
R19, R22: 100k; R_0603_1608Metric; LCSCPart C25803
R32, R40, R45, R48, R51: 1k; R_0603_1608Metric; LCSCPart C14676
SW1, SW2, SW5: SW_SPDT; SW-SMD_K3-1235S-K1; LCSCPart C92660
SW3, SW4: SW_Push; KEY-SMD_4P-L6.0-W6.0-P4.50-LS10.0; LCSCPart C83916
TH1: 10K; R_0603_1608Metric; LCSCPart C13564
U1: TPS62082DSGR; LCSCPart C485809
U2: BQ27441DRZR-G1B; LCSCPart C473374
U3: USBLC6-2SC6; LCSCPart C7519
U4: BQ24074RGTR; LCSCPart C54313
U5: TS3USB221ARSER; LCSC Part C128396
U6: TPS63002DRCT; TPS63002DRCR; LCSCPart C116655
U7: STM32F411CEU6; LCSCPart C60420
U8: ESP32-C3-MINI-1-H4; LCSCPart C2934569
USB1: USB-310F-B-SU; LCSCPart C309365
Y1: 12.5pF; Crystal_SMD_3215-2Pin_3.2x1.5mm; LCSCPart C130253
Y2: 18pF; Crystal_SMD_3225-4Pin_3.2x2.5mm; LCSCPart C179641

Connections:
/BAT: BAT1.1 (+), C6.2, R11.2, U2.6 (BAT), U2.8 (SRP)
/BCK5_EN: C10.2, R25.1, U6.6 (EN), U6.7 (PS/SYNC), U6.8 (VINA)
/BOOT0: R26.2, U7.44 (BOOT0)
/BUZPWM: R42.2, U7.29 (PA8)
/CC1: R7.1, USB1.6 (CC1)
/CC2: R8.1, USB1.12 (CC2)
/CHG_#CHG: R19.2, U4.9 (~CHG), U7.28 (PB15)
/CHG_#PGOOD: R22.2, U4.7 (~PGOOD), U7.27 (PB14)
/CONFSW: C36.1, CON1.14, R49.2, R51.1
/CONFSW_DB: R51.2, U7.41 (PB5)
/ENRST: C29.1, C32.1, R39.1, SW4.1, U8.8 (EN)
/FG_BIN: R4.1, U2.10 (BIN)
/FG_GPOUT: R5.1, U2.12 (GPOUT), U7.26 (PB13)
/FG_SCL: R1.1, R36.2, U2.2 (SCL), U7.21 (PB10)
/FG_SDA: R2.1, R37.2, U2.1 (SDA), U7.39 (PB3)
/HOSW: C35.1, CON1.16, R41.2, R45.1
/HOSW_DB: R45.2, U7.45 (PB8)
/HSE_IN: C18.1, U7.5 (PH0-OSC_IN), Y2.1
/HSE_OUT: C19.2, U7.6 (PH1-OSC_OUT), Y2.3
/IICDISP_SCL: CON1.9, R31.2, U7.42 (PB6)
/IICDISP_SDA: CON1.10, R30.1, U7.43 (PB7)
/ILIM: R10.2, U4.12 (ILIM)
/ISET: R6.2, U4.16 (ISET)
/ITERM: R9.2, U4.15 (ITERM)
/LEDCHPWM: CON1.18, R35.1
/LEDHOPWM: CON1.20, R29.2
/LSE_IN: C16.1, U7.3 (PC14-OSC32_IN), Y1.2
/LSE_OUT: C17.2, U7.4 (PC15-OSC32_OUT), Y1.1
/NRST: C20.2, SW3.2, U7.7 (NRST)
/PANICGPIO: CON1.26, U7.25 (PB12)
/PANICPWM: CON1.25, U7.46 (PB9)
/SERVOPWM1: CON1.1, U7.16 (PA6)
/SERVOPWM2: CON1.2, U7.17 (PA7)
/SERVOPWM3: CON1.3, U7.18 (PB0)
/SERVOPWM4: CON1.4, U7.19 (PB1)
/SERVOPWM5: CON1.11, U7.10 (PA0-WKUP)
/SERVOPWM6: CON1.22, U7.11 (PA1)
/STM_UARTRX: R33.1, U7.31 (PA10)
/STM_UARTTX: R34.1, U7.30 (PA9)
/SW_BOOT0: D5.1 (K), D6.2 (A), R20.1, R26.1
/SW_BOOTE0: D8.1 (K), D9.2 (A), R43.1, SW5.2 (B)
/TS: TH1.1, U4.1 (TS)
/UARTRX_ESP: R33.2, U8.31 (TXD0)
/UARTTX_ESP: R34.2, U8.30 (RXD0)
/USB_D+: U3.3, U3.4, U5.8 (D+), USB1.8 (D+), USB1.10 (D+)
/USB_D-: U3.1, U3.6, U5.7 (D-), USB1.7 (D-), USB1.9 (D-)
/USB_DESP+: U5.3 (2D+), U8.27 (IO19)
/USB_DESP-: U5.4 (2D-), U8.26 (IO18)
/USB_DSTM+: U5.1 (1D+), U7.33 (PA12)
/USB_DSTM-: U5.2 (1D-), U7.32 (PA11)
/USB_SLC: R14.2, U5.9 (S)
/VDDASTM: C22.2, C25.2, FB1.2, U7.9 (VREF+)
BATSYS: J4.1, R11.1, U2.7 (SRN), U4.2 (BAT), U4.3 (BAT)
BCKOUT5: BZ1.1 (+), C2.2, C26.2, C27.2, CON1.5, CON1.7, CON1.12, CON1.23, D7.2 (A), J2.1, R48.2, U1.1 (EN), U1.8 (VIN), U6.1 (VOUT), U6.10 (FB)
BCKOUT33: C4.2, C5.2, C13.2, C28.1, C30.1, C31.1, C33.1, C37.2, CON1.19, CON1.21, D4.2 (A), FB1.1, J1.1, L1.2, Q1.3 (E), R1.2, R2.2, R5.2, R19.1, R22.1, R23.1, R30.2, R31.1, R36.1, R37.1, R38.1, R39.2, R41.1, R44.2, R49.1, SW1.3 (C), SW2.3 (C), SW5.3 (C), U1.5 (VOS), U5.10 (VCC), U8.3 (3V3)
BCOUT: C7.2, C8.2, R21.2, U4.5 (EN2), U4.10 (OUT), U4.11 (OUT), U6.5 (VIN)
GNDA: C13.1, C22.1, C25.1, NT1.1, U7.8 (VSSA)
GNDD: BAT1.2 (-), C1.2, C2.1, C3.2, C4.1, C5.1, C6.1, C7.1, C8.1, C9.1, C10.1, C11.1, C12.1, C14.1, C15.1, C16.2, C17.1, C18.2, C19.1, C20.1, C21.1, C23.1, C24.1, C26.1, C27.1, C28.2, C29.2, C30.2, C31.2, C32.2, C33.2, C34.1, C35.2, C36.2, C37.1, CON1.6, CON1.8, CON1.13, CON1.15, CON1.17, CON1.24, J5.1, NT1.2, Q2.3 (E), Q3.3 (E), R4.2, R6.1, R7.2, R8.2, R9.1, R10.1, R12.1, R13.1, SW1.1 (A), SW2.1 (A), SW3.1, SW4.2, SW5.1 (A), TH1.2, U1.2 (GND), U1.3 (MODE), U1.9 (GND), U1.9_1 (GND), U1.9_2 (GND), U2.3 (VSS), U2.13 (EXP), U3.2, U4.6 (EN1), U4.8 (VSS), U4.14 (TMR), U4.17 (EXP), U4.18, U5.5 (GND), U6.3 (PGND), U6.9 (GND), U6.11 (PP), U6.12, U6.13, U6.14, U6.15, U7.23 (VSS), U7.35 (VSS), U7.47 (VSS), U7.49 (VSS), U7.50, U8.1 (GND), U8.2 (GND), U8.11 (GND), U8.14 (GND), U8.36 (GND), U8.37 (GND), U8.38 (GND), U8.39 (GND), U8.40 (GND), U8.41 (GND), U8.42 (GND), U8.43 (GND), U8.44 (GND), U8.45 (GND), U8.46 (GND), U8.47 (GND), U8.48 (GND), U8.49 (GND), U8.50 (GND), U8.51 (GND), U8.52 (GND), U8.53 (GND), USB1.1 (GND), USB1.2 (GND), USB1.15 (GND), USB1.16 (GND), Y2.2, Y2.4
LGND: Q2.1 (C), R3.1, R16.2, R18.1, R27.1, R28.1, R50.1
LVCC: Q1.1 (C), R17.2, R24.2, R40.1, R47.2
unnamed: BZ1.2 (-), Q3.1 (C), R48.1
unnamed: D1.1 (K), R3.2
unnamed: D2.2 (A), D3.1 (K), R15.1, SW1.2 (B)
unnamed: D2.1 (K), R16.1
unnamed: D3.2 (A), R17.1
unnamed: D4.1 (K), R18.2
unnamed: D5.2 (A), R24.1
unnamed: D6.1 (K), R27.2
unnamed: D7.1 (K), R28.2
unnamed: D8.2 (A), R47.1
unnamed: D9.1 (K), R50.2
unnamed: Q1.2 (B), R32.2
unnamed: Q2.2 (B), R40.2
unnamed: Q3.2 (B), R42.1
unnamed: R14.1, R15.2
unnamed: R21.1, R25.2
unnamed: R43.2, R46.1
unnamed: R20.2, SW2.2 (B)
unnamed: L1.1, U1.7 (SW)
unnamed: C3.1, U2.5 (VDD)
unnamed: R13.2, U4.4 (~CE)
unnamed: R12.2, U5.6 (~OE)
unnamed: L2.1, U6.4 (L1)
unnamed: L2.2, U6.2 (L2)
unnamed: R35.2, U7.12 (PA2)
unnamed: R29.1, U7.13 (PA3)
unnamed: R32.1, U7.37 (PA14)
unnamed: C23.2, U7.22 (VCAP_1)
unnamed: C34.2, R38.2, U8.5 (IO2)
unnamed: R44.1, U8.22 (IO8)
unnamed: R46.2, U8.23 (IO9)
VBUS: C1.1, D1.2 (A), J3.1, U3.5, U4.13 (IN), USB1.3 (VBUS), USB1.4 (VBUS), USB1.13 (VBUS), USB1.14 (VBUS)
VDD: C9.2, C11.2, C12.2, C14.2, C15.2, C21.2, C24.2, R23.2, U7.1 (VBAT), U7.24 (VDD), U7.36 (VDD), U7.48 (VDD)

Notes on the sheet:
Vin=0 VBAT=BAT
GPIO9 == 1 | SPI Memory Run GPIO9 == 0 | Joint Download (USB)
L=STM32 H=ESP32
TIM1
PWM Buzzer Driver
STM32F411CE MCU
Birač za USB Input Source
TIM4
IIC "Pull-up" otpornici.
TIM2
TIM3
Čišćenje signala od šuma za analogno napajanje.
LSE (Low Speed External) Clock.
Buck-Boost Fixed 5V Converter
Switch Debounce Suppressor
USB-C Konektor, [USBLC6-2SC6] TVS Diode Protection i [TS3USB221ARSER] 1:2 Multiplexer za USB Host
ESP32-C3 MINI 1
Battery Fuel Gauge IC
[BQ24074RGTR] IC za punjenje i pražnjenje baterije.
HSE (High Speed External) Clock.
Čišćenje signala od šuma za digitalno napajanje.
[TPS63002DRCT] Fiksni 5V Boost konverter BCOUT(BQ24074RGTR)-->BCKOUT5(TPS63002DRCT)
LED Debug mode picker.
Buck-Boost Fixed 3.3V Converter
Boot memory picker.
South Bus IDC
USB-C Connector
Misc
Battery Charging IC
[BQ27441DRZR-G1B] IC za praćenje stanja baterije i [BAT1 (SAMSUNG20R)] 2000mAh baterija.
[TPS62082DSGR] Fiksni 3.3V Step-Down konverter BCKOUT5(TPS63002DRCT)-->BCKOUT33(TPS62082DSGR)
Montažne Tačke
Reset.

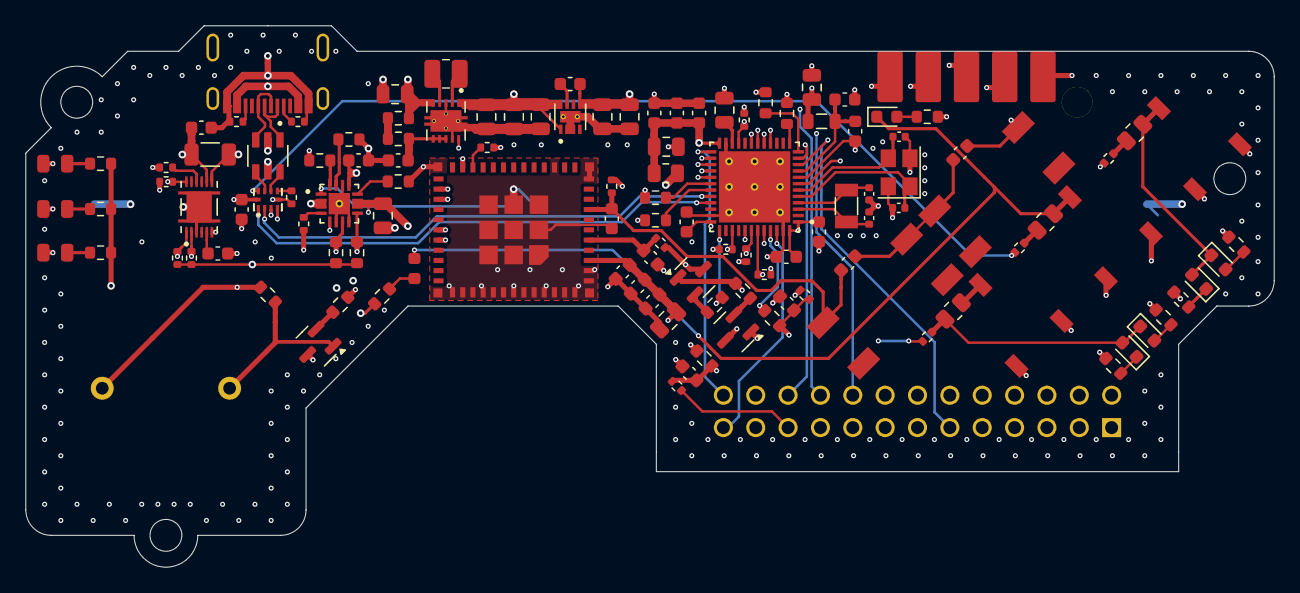
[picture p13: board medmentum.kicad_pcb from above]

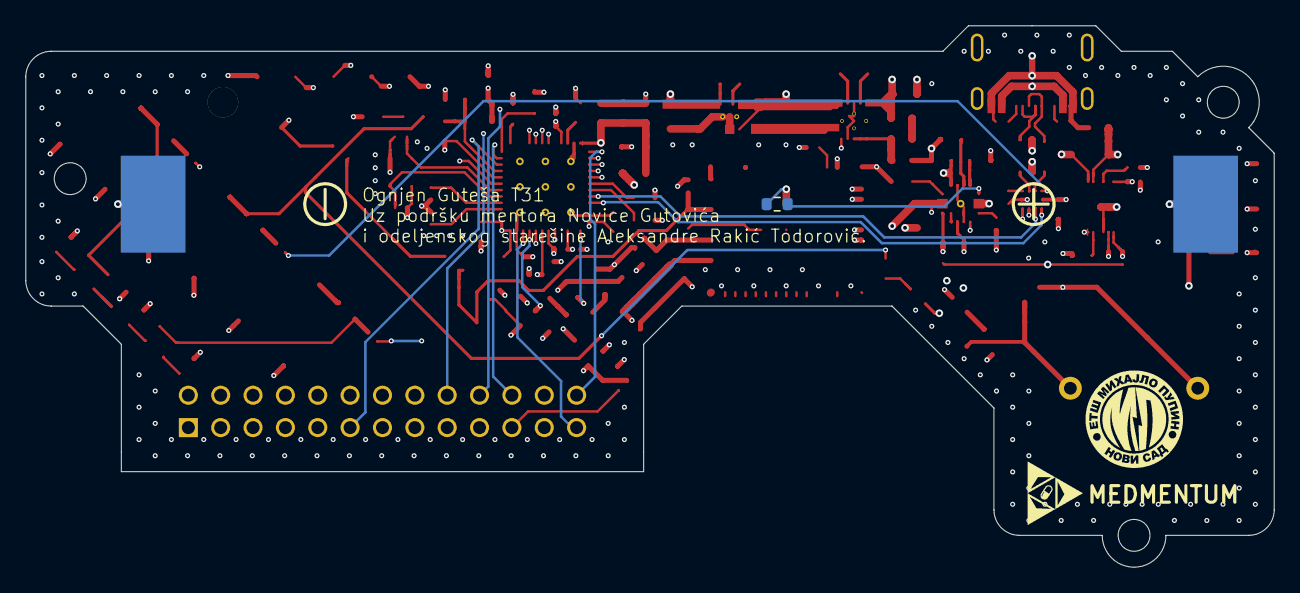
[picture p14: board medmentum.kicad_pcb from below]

Board: 6 copper layers, 98.0 x 42.5 mm, 132 parts (3 on the bottom side), 93 nets.

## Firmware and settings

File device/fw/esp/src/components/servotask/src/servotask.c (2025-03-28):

#include "freertos/FreeRTOS.h"
#include "freertos/task.h"
#include "esp_log.h"
#include "mcpwm_prelude.h"

#include "servotask.h"
#include "esp_log.h"

static const char *TAG = "Servo360";

#define SERVO_TIMEBASE_HZ   1000000 // 1MHz = 1μs rezolucija
#define SERVO_PERIOD_TICKS  20000   // 20ms period (standard za servo)

void servoinit(servocfg *servo, int gpio_num) {
    // Konfiguracija tajmera
    mcpwm_timer_config_t timer_cfg = {
        .group_id = 0,
        .clk_src = MCPWM_TIMER_CLK_SRC_DEFAULT,
        .resolution_hz = SERVO_TIMEBASE_HZ,
        .period_ticks = SERVO_PERIOD_TICKS,
        .count_mode = MCPWM_TIMER_COUNT_MODE_UP,
    };
    ESP_ERROR_CHECK(mcpwm_new_timer(&timer_cfg, &servo->timer));

    // Konfiguracija operatora
    mcpwm_operator_config_t oper_cfg = { .group_id = 0 };
    ESP_ERROR_CHECK(mcpwm_new_operator(&oper_cfg, &servo->oper));

    // Poveži timer i operator
    ESP_ERROR_CHECK(mcpwm_operator_connect_timer(servo->oper, servo->timer));

    // Komparator (određuje širinu pulsa)
    mcpwm_comparator_config_t cmp_cfg = { .flags.update_cmp_on_tez = true };
    ESP_ERROR_CHECK(mcpwm_new_comparator(servo->oper, &cmp_cfg, &servo->comparator));

    // Generator (izlaz na GPIO)
    mcpwm_generator_config_t gen_cfg = { .gen_gpio_num = gpio_num };
    ESP_ERROR_CHECK(mcpwm_new_generator(servo->oper, &gen_cfg, &servo->generator));

    // Postavi akcije:
    // - VISOK nivo na početku periode
    // - NISK nivo kada komparator dostigne vrednost
    ESP_ERROR_CHECK(mcpwm_generator_set_action_on_timer_event(
        servo->generator,
        MCPWM_GEN_TIMER_EVENT_ACTION(MCPWM_TIMER_DIRECTION_UP, MCPWM_TIMER_EVENT_EMPTY, MCPWM_GEN_ACTION_HIGH)
    ));
    ESP_ERROR_CHECK(mcpwm_generator_set_action_on_compare_event(
        servo->generator,
        MCPWM_GEN_COMPARE_EVENT_ACTION(MCPWM_TIMER_DIRECTION_UP, servo->comparator, MCPWM_GEN_ACTION_LOW)
    ));

    // Pokreni timer
    ESP_ERROR_CHECK(mcpwm_timer_enable(servo->timer));
    ESP_ERROR_CHECK(mcpwm_timer_start_stop(servo->timer, MCPWM_TIMER_START_NO_STOP));
}

void servosetspeed(servocfg *servo, uint32_t pulse_width_us) {
    ESP_ERROR_CHECK(mcpwm_comparator_set_compare_value(servo->comparator, pulse_width_us));
}

void servostop(servocfg *servo) {
    servosetspeed(servo, SERVO_STOP_US);
}

void servofull_cw(servocfg *servo) {
    servosetspeed(servo, SERVO_FULL_CW_US);
}

void servofull_ccw(servocfg *servo) {
    servosetspeed(servo, SERVO_FULL_CCW_US);
}

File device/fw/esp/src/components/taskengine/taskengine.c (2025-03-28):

#include "freertos/FreeRTOS.h"
#include "freertos/task.h"
#include "esp_log.h"
#include "captiveportal.h"
#include "hal/gpio_types.h"
#include "servotask.h"
#include "soc/gpio_num.h"
#include "wifitask.h"
#include "mqtt.h"
#include <stdbool.h>
#include <time.h>
#include "esp_intr_alloc.h"        
#include "esp_attr.h"            
#include "driver/rtc_io.h"  
#include "driver/gpio.h"


#define GPIO_INPUT_PIN      GPIO_NUM_12

static const char *TAG = "TaskEngine";

// Globalne promenljive za praćenje stanja
static bool wifi_credentials_received = false;
static bool wifi_connected = false;
static bool mqtt_connected = false;

volatile bool enable_button = false;
volatile bool start_servo_flag = false;


// Handler za MQTT poruke
static void mqtt_message_handler(const char* topic, const char* data, int len)
{
    ESP_LOGI(TAG, "Primljena MQTT poruka:\nTopic: %s\nData: %.*s", topic, len, data);
}

void startservo2(){
	servocfg servo;
	servoinit(&servo, 15);
	ESP_LOGI("MAIN", "Puna brzina u CW smeru (otvaranje fioke)");
    servofull_ccw(&servo);
    vTaskDelay(pdMS_TO_TICKS(7000));  // 2 sekunde

    ESP_LOGI("MAIN", "Stop");
    servostop(&servo);
    vTaskDelay(pdMS_TO_TICKS(1000));  // 1 sekunda
    
    ESP_LOGI("MAIN", "Puna brzina u CCW smeru (otvaranje fioke)");
    servofull_cw(&servo);
    vTaskDelay(pdMS_TO_TICKS(7000));  // 2 sekunde
    
    ESP_LOGI("MAIN", "Stop");
    servostop(&servo);
}

void startservo4(){
	servocfg servo;
	servoinit(&servo, 2);
	ESP_LOGI("MAIN", "Puna brzina u CW smeru (otvaranje fioke)");
    servofull_ccw(&servo);
    vTaskDelay(pdMS_TO_TICKS(7000));  // 2 sekunde

    ESP_LOGI("MAIN", "Stop");
    servostop(&servo);
    vTaskDelay(pdMS_TO_TICKS(1000));  // 1 sekunda
    
    ESP_LOGI("MAIN", "Puna brzina u CCW smeru (otvaranje fioke)");
    servofull_cw(&servo);
    vTaskDelay(pdMS_TO_TICKS(7000));  // 2 sekunde
    
    ESP_LOGI("MAIN", "Stop");
    servostop(&servo);
    vTaskDelay(pdMS_TO_TICKS(500));
    
}

void startservofio(){
	servocfg servo;
	servoinit(&servo, 4);
	ESP_LOGI("MAIN", "Puna brzina u CW smeru (otvaranje fioke)");
    servofull_ccw(&servo);
    vTaskDelay(pdMS_TO_TICKS(3000));  // 2 sekunde

    ESP_LOGI("MAIN", "Stop");
    servostop(&servo);
    vTaskDelay(pdMS_TO_TICKS(15000));  // 1 sekunda
    
    ESP_LOGI("MAIN", "Puna brzina u CCW smeru (otvaranje fioke)");
    servofull_cw(&servo);
    vTaskDelay(pdMS_TO_TICKS(3000));  // 2 sekunde
    
    ESP_LOGI("MAIN", "Stop");
    servostop(&servo);
    vTaskDelay(pdMS_TO_TICKS(500));
    
}

void servostarter(void){
	//servo police D5
	startservo2();
	vTaskDelay(pdMS_TO_TICKS(500));
	startservo4();
	vTaskDelay(pdMS_TO_TICKS(500));
	startservofio();
}


void internetstack(void)
{
	
    // 1. Inicijalizacija sistema
    ESP_LOGI(TAG, "Pokrećem sistem...");
    
    // 2. Pokretanje Captive Portala
    ESP_LOGI(TAG, "Pokrećem Captive Portal...");
    captiveportal_init();
    
    // 3. Glavna petlja čekanja WiFi kredencijala
    while(1) {
        char ssid[32] = {0};
        char password[64] = {0};
        
        // Provera da li su kredencijali primljeni preko portala
        if (get_wifi_credentials(ssid, password, sizeof(ssid))) {
            ESP_LOGI(TAG, "Primljeni WiFi kredencijali:");
            ESP_LOGI(TAG, "SSID: %s", ssid);
            ESP_LOGI(TAG, "Password: %s", password);
            
            // Zaustavi Captive Portal
            captiveportal_stop();
            wifi_credentials_received = true;
            
            // 4. Povezivanje na WiFi
            ESP_LOGI(TAG, "Pokušavam povezivanje na WiFi...");
            wifi_init(); // Ovo postavlja kredencijale iz captive portala
            wifi_connect();
            
            break; // Izlaz iz petlje čekanja kredencijala
        }
        
        vTaskDelay(1000 / portTICK_PERIOD_MS);
    }
    
    // 5. Čekanje WiFi konekcije
    while(wifi_credentials_received && !wifi_connected) {
        if (is_wifi_connected()) {
            wifi_connected = true;
            ESP_LOGI(TAG, "WiFi uspešno povezan!");
        }
        vTaskDelay(1000 / portTICK_PERIOD_MS);
    }
    
    // 6. Pokretanje MQTT nakon WiFi konekcije
    if (wifi_connected) {

        ESP_LOGI(TAG, "Pokrećem MQTT klijent...");
        mqtt_client_init("mqtt://164.92.187.3", "ognjen", "elektropionir");
        mqtt_set_callback(mqtt_message_handler);
        mqtt_subscribe("device/commands", 1);
        mqtt_connected = true;
    }
    
    // 7. Glavna radna petlja (sa MQTT komunikacijom)
    int counter = 0;
    while(1) {
        if (wifi_connected && mqtt_connected) {
            // Slanje periodičnih status poruka
            char msg[50];
            snprintf(msg, sizeof(msg), "Status %d", counter++);
            mqtt_publish("device/status", msg, 1);
            ESP_LOGI(TAG, "Poslata MQTT poruka: %s", msg);
        }
        
        // Provera WiFi i MQTT stanja
        wifi_connected = is_wifi_connected();
        
        if (wifi_connected && !mqtt_connected) {
            // Ponovno pokretanje MQTT ako je WiFi povratak
            mqtt_client_init("mqtt://164.92.187.3", "ognjen", "elektropionir");
            mqtt_subscribe("device/commands", 1);
            mqtt_connected = true;
        }
        
        vTaskDelay(5000 / portTICK_PERIOD_MS);
    }
    
}

void button_task(void *arg) {
    gpio_set_direction(GPIO_INPUT_PIN , GPIO_MODE_INPUT);
    gpio_set_pull_mode(GPIO_INPUT_PIN , GPIO_PULLDOWN_ENABLE);  // Dugme aktivno LOW

    bool last_button_state = 0;  // Inicijalno HIGH (nije pritisnuto)
    while (1) {
        bool current_button_state = gpio_get_level(GPIO_INPUT_PIN );
        
        if (current_button_state == 1 && last_button_state == 0) {
            ESP_LOGI(TAG, "Dugme pritisnuto!");
            
            if (wifi_connected) {
                servostarter();  // Pokreni servo samo ako je WiFi povezan
            } else {
                ESP_LOGE(TAG, "WiFi NIJE povezan! Servo se ne pokreće.");
            }
        }
        last_button_state = current_button_state;
        vTaskDelay(20 / portTICK_PERIOD_MS);  // Debounce delay (20ms)
    }
}

void TaskEngine(){
	internetstack();
	xTaskCreate(button_task, "button_task", 2048, NULL, 10, NULL);
}

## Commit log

2025-01-13 Add File Structure
    [medmentum.kicad_pcb, medmentum.kicad_sch]
2025-01-15 Add sheets
    [bms.kicad_sch, esp32_mcu.kicad_sch, north_bridge.kicad_sch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]
